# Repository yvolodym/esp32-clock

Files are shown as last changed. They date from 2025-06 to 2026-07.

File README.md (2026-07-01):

# esp32-clock

This project is intended as training for esp8266. The aim of this project is to develop a low-energy clock, developed in C by [espressif](https://www.espressif.com/) with associated PCB in [KiCad](https://www.kicad.org/).

### URI
* https://docs.lvgl.io/master/intro/introduction.html
* https://github.com/espressif/esp-bsp/tree/master/components/lcd/esp_lcd_gc9a01
* https://github.com/espressif/esp-bsp
* https://github.com/lvgl/lv_port_esp32
* https://github.com/lvgl/lvgl_esp32_drivers/blob/master/README.md

### HARDWARE
ESP32-PICO-V3
CR2032

### Software
* https://github.com/espressif/esp-idf/blob/master/examples/peripherals/lcd/spi_lcd_touch/README.md
-------------------------------
* https://github.com/espressif/esp-idf/tree/v5.4/examples/peripherals/lcd/i2c_oled/main
* https://github.com/UsefulElectronics/esp32s3-gc9a01-lvgl/blob/main/main/Kconfig.projbuild
* https://github.com/liyanboy74/gc9a01-esp-idf
* https://github.com/somebox/esp32-GC9A01-round/blob/main/src/main.cpp

### Schematik
* https://embeddedprojects101.com/design-a-battery-powered-stm32-board-with-usb/

### JLCPCB
* https://jlcpcb.com/parts/componentSearch

### Video
* https://www.youtube.com/watch?v=S_p0YV-JlfU

### WIFI Provisioning
* https://docs.espressif.com/projects/esp-idf/en/stable/esp32/api-reference/provisioning/wifi_provisioning.html#
* https://github.com/espressif/esp-idf/blob/master/examples/provisioning/wifi_prov_mgr/README.md

| Pin | Name |
|-----|---|
|IO19 |RST |
|IO10 |SCL |
|IO20 |CS |
|IO21 |DC |
|IO22 |MOSI  |

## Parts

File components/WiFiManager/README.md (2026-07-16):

# WiFiManager

Espressif ESPx WiFi Connection manager with fallback web configuration portal

:warning: This Documentation is out of date, see notes below


















Member to Member Support / Chat

 
 

The configuration portal is of the captive variety, so on various devices it will present the configuration dialogue as soon as you connect to the created access point.

Works with the [ESP8266 Arduino](https://github.com/esp8266/Arduino) and [ESP32 Arduino](https://github.com/espressif/arduino-esp32) platforms.

### Known Issues

* Documentation needs to be updated, see [https://github.com/tzapu/WiFiManager/issues/500](https://github.com/tzapu/WiFiManager/issues/500)
-------

## Contents
 - [How it works](#how-it-works)
 - [Wishlist](#wishlist)
 - [Quick start](#quick-start)
   - Installing
     - [Arduino - Through Library Manager](#install-through-library-manager)
     - [Arduino - From Github](#checkout-from-github)
     - [PlatformIO](#install-using-platformio)
   - [Using](#using)
 - [Documentation](#documentation)
   - [Access Point Password](#password-protect-the-configuration-access-point)
   - [Callbacks](#callbacks)
   - [Configuration Portal Timeout](#configuration-portal-timeout)
   - [On Demand Configuration](#on-demand-configuration-portal)
   - [Custom Parameters](#custom-parameters)
   - [Custom IP Configuration](#custom-ip-configuration)
   - [Filter Low Quality Networks](#filter-networks)
   - [Debug Output](#debug)
 - [Troubleshooting](#troubleshooting)
 - [Releases](#releases)
 - [Contributors](#contributions-and-thanks)

## How It Works
- When your ESP starts up, it sets it up in Station mode and tries to connect to a previously saved Access Point
- if this is unsuccessful (or no previous network saved) it moves the ESP into Access Point mode and spins up a DNS and WebServer (default ip 192.168.4.1)
- using any wifi enabled device with a browser (computer, phone, tablet) connect to the newly created Access Point
- because of the Captive Portal and the DNS server you will either get a 'Join to network' type of popup or get any domain you try to access redirected to the configuration portal
- choose one of the access points scanned, enter password, click save
- ESP will try to connect. If successful, it relinquishes control back to your app. If not, reconnect to AP and reconfigure.
- There are options to change this behavior or manually start the configportal and webportal independantly as well as run them in non blocking mode.

## How It Looks
ESP8266 WiFi Captive Portal Homepage ESP8266 WiFi Captive Portal Configuration

## Wishlist
- [x] remove dependency on EEPROM library
- [x] move HTML Strings to PROGMEM
- [x] cleanup and streamline code (although this is ongoing)
- [x] if timeout is set, extend it when a page is fetched in AP mode
- [x] add ability to configure more parameters than ssid/password
- [x] maybe allow setting ip of ESP after reboot
- [x] add to Arduino Library Manager
- [x] add to PlatformIO
- [ ] add multiple sets of network credentials
- [x] allow users to customize CSS
- [ ] rewrite documentation for simplicity, based on scenarios/goals

### Development
- [x] ESP32 support
- [x] rely on the SDK's built in auto connect more than forcing a connect
- [x] add non blocking mode
- [x] easy customization of strings
- [x] hostname support
- [x] fix various bugs and workarounds for esp SDK issues
- [x] additional info page items
- [x] last status display / faiilure reason
- [x] customizeable menu
- [x] seperate custom params page
- [x] ondemand webportal
- [x] complete refactor of code to segment functions
- [x] wiif scan icons or percentage display
- [x] invert class for dark mode
- [x] more template tokens
- [x] progmem for all strings
- [ ] new callbacks
- [ ] new callouts / filters
- [ ] shared web server instance
- [x] latest esp idf/sdk support
- [x] wm is now non persistent, will not erase or change stored esp config on esp8266
- [x] tons of debugging output / levels
- [ ] disable captiveportal
- [ ] preload wiifscans, faster page loads
- [ ] softap stability fixes when sta is not connected

## Quick Start

### Installing
You can either install through the Arduino Library Manager or checkout the latest changes or a release from github

#### Install through Library Manager
__Currently version 0.8+ works with release 2.4.0 or newer of the [ESP8266 core for Arduino](https://github.com/esp8266/Arduino)__
 - in Arduino IDE got to Sketch/Include Library/Manage Libraries
  Manage Libraries

 - search for WiFiManager
  WiFiManager package

 - click Install and start [using it](#using)

####  Checkout from github
__Github version works with release 2.4.0 or newer of the [ESP8266 core for Arduino](https://github.com/esp8266/Arduino)__
- Checkout library to your Arduino libraries folder

### Using
- Include in your sketch
```cpp
#include <WiFiManager.h>          //https://github.com/tzapu/WiFiManager WiFi Configuration Magic
```

- Initialize library, in your setup function add, NOTEif you are using non blocking you will make sure you create this in global scope or handle appropriatly , it will not work if in setup and using non blocking mode.
```cpp
WiFiManager wifiManager;
```

- Also in the setup function add
```cpp
//first parameter is name of access point, second is the password
wifiManager.autoConnect("AP-NAME", "AP-PASSWORD");
```
if you just want an unsecured access point
```cpp
wifiManager.autoConnect("AP-NAME");
```
or if you want to use and auto generated name from 'ESP' and the esp's Chip ID use
```cpp
wifiManager.autoConnect();
```

After you write your sketch and start the ESP, it will try to connect to WiFi. If it fails it starts in Access Point mode.
While in AP mode, connect to it then open a browser to the gateway IP, default 192.168.4.1, configure wifi, save and it should reboot and connect.

Also see [examples](https://github.com/tzapu/WiFiManager/tree/master/examples).

#### Install Using PlatformIO

[PlatformIO](https://platformio.org/) is an emerging ecosystem for IoT development, and 
is an alternative to using the Arduino IDE. Install `WiFiManager`
using the platformio [library manager](https://docs.platformio.org/en/latest/librarymanager/index.html#librarymanager) in your editor, 
or using the [PlatformIO Core CLI](https://docs.platformio.org/en/latest/core/index.html),
or by adding it to your `platformio.ini` as shown below (recommended approach).

The simplest way is to open the `platformio.ini` file at the root of your project, and `WifiManager` to the common top-level env
`lib_deps` key like so:

```
[env]
lib_deps =
	WiFiManager
```

```
[env]
lib_deps =
	https://github.com/tzapu/WiFiManager.git
```

## Documentation

#### Switch languages for the configuration website
You can switch the language for configuration website during compile time. Default is `LANG_EN` for an english setup. Within PlatformIO add the following compile parameter:
```ini
[env]
build_flags = -D LANG_EN
```
Currently the following language codes are available:
```ini
LANG_DE
LANG_EN
LANG_ES
LANG_FR
LANG_PT
LANG_PT_BR
```

#### Password protect the configuration Access Point
You can and should password protect the configuration access point.  Simply add the password as a second parameter to `autoConnect`.
A short password seems to have unpredictable results so use one that's around 8 characters or more in length.
The guidelines are that a wifi password must consist of 8 to 63 ASCII-encoded characters in the range of 32 to 126 (decimal)
```cpp
wifiManager.autoConnect("AutoConnectAP", "password")
```

#### Callbacks
##### Enter Config mode
Use this if you need to do something when your device enters configuration mode on failed WiFi connection attempt.
Before `autoConnect()`
```cpp
wifiManager.setAPCallback(configModeCallback);
```
`configModeCallback` declaration and example
```cpp
void configModeCallback (WiFiManager *myWiFiManager) {
  Serial.println("Entered config mode");
  Serial.println(WiFi.softAPIP());

  Serial.println(myWiFiManager->getConfigPortalSSID());
}
```

##### Save settings
This gets called when custom parameters have been set **AND** a connection has been established. Use it to set a flag, so when all the configuration finishes, you can save the extra parameters somewhere.

IF YOU NEED TO SAVE PARAMETERS EVEN ON WIFI FAIL OR EMPTY, you must set `setBreakAfterConfig` to true, or else saveConfigCallback will not be called.

```C++
//if this is set, it will exit after config, even if connection is unsuccessful.
    void          setBreakAfterConfig(boolean shouldBreak);
```

See [AutoConnectWithFSParameters Example](https://github.com/tzapu/WiFiManager/tree/master/examples/Parameters/SPIFFS/AutoConnectWithFSParameters).
```cpp
wifiManager.setSaveConfigCallback(saveConfigCallback);
```
`saveConfigCallback` declaration and example
```cpp
//flag for saving data
bool shouldSaveConfig = false;

//callback notifying us of the need to save config
void saveConfigCallback () {
  Serial.println("Should save config");
  shouldSaveConfig = true;
}
```

#### Configuration Portal Timeout
If you need to set a timeout so the ESP doesn't hang waiting to be configured, for instance after a power failure, you can add
```cpp
wifiManager.setConfigPortalTimeout(180);
```
which will wait 3 minutes (180 seconds). When the time passes, the autoConnect function will return, no matter the outcome.
Check for connection and if it's still not established do whatever is needed (on some modules I restart them to retry, on others I enter deep sleep)

#### On Demand Configuration Portal
If you would rather start the configuration portal on demand rather than automatically on a failed connection attempt, then this is for you.

Instead of calling `autoConnect()` which does all the connecting and failover configuration portal setup for you, you need to use `startConfigPortal()`. __Do not use BOTH.__

Example usage
```cpp
void loop() {
  // is configuration portal requested?
  if ( digitalRead(TRIGGER_PIN) == LOW ) {
    WiFiManager wifiManager;
    wifiManager.startConfigPortal("OnDemandAP");
    Serial.println("connected...yeey :)");
  }
}
```
See example for a more complex version. [OnDemandConfigPortal](https://github.com/tzapu/WiFiManager/tree/master/examples/OnDemand/OnDemandConfigPortal)

#### Exiting from the Configuration Portal
Normally, once entered, the configuration portal will continue to loop until WiFi credentials have been successfully entered or a timeout is reached.
If you'd prefer to exit without joining a WiFi network, say becuase you're going to put the ESP into AP mode, then press the "Exit" button
on the main webpage.
If started via `autoConnect` or `startConfigPortal` then it will return `false (portalAbortResult)`

#### Custom Parameters
You can use WiFiManager to collect more parameters than just SSID and password.
This could be helpful for configuring stuff like MQTT host and port, [blynk](http://www.blynk.cc) or [emoncms](http://emoncms.org) tokens, just to name a few.
**You are responsible for saving and loading these custom values.** The library just collects and displays the data for you as a convenience.
Usage scenario would be:
- load values from somewhere (EEPROM/FS) or generate some defaults
- add the custom parameters to WiFiManager using
```cpp
 // id/name, placeholder/prompt, default, length
 WiFiManagerParameter custom_mqtt_server("server", "mqtt server", mqtt_server, 40);
 wifiManager.addParameter(&custom_mqtt_server);

```
- if connection to AP fails, configuration portal starts and you can set /change the values (or use on demand configuration portal)
- once configuration is done and connection is established save config callback() is called
- once WiFiManager returns control to your application, read and save the new values using the `WiFiManagerParameter` object.
```cpp
 mqtt_server = custom_mqtt_server.getValue();
```  
This feature is a lot more involved than all the others, so here are some examples to fully show how it is done.
You should also take a look at adding custom HTML to your form.

- Save and load custom parameters to file system in json form [AutoConnectWithFSParameters](https://github.com/tzapu/WiFiManager/tree/master/examples/Parameters/SPIFFS/AutoConnectWithFSParameters)
- *Save and load custom parameters to EEPROM* (not done yet)

#### Custom IP Configuration
You can set a custom IP for both AP (access point, config mode) and STA (station mode, client mode, normal project state)

##### Custom Access Point IP Configuration
This will set your captive portal to a specific IP should you need/want such a feature. Add the following snippet before `autoConnect()`
```cpp
//set custom ip for portal
wifiManager.setAPStaticIPConfig(IPAddress(10,0,1,1), IPAddress(10,0,1,1), IPAddress(255,255,255,0));
```

##### Custom Station (client) Static IP Configuration
This will make use the specified IP configuration instead of using DHCP in station mode.
```cpp
wifiManager.setSTAStaticIPConfig(IPAddress(192,168,0,99), IPAddress(192,168,0,1), IPAddress(255,255,255,0)); // optional DNS 4th argument
```
There are a couple of examples in the examples folder that show you how to set a static IP and even how to configure it through the web configuration portal.

NOTE: You should fill DNS server if you have HTTP requests with hostnames or syncronize time (NTP). It's the same as gateway ip or a popular (Google DNS: 8.8.8.8).

#### Custom HTML, CSS, Javascript
There are various ways in which you can inject custom HTML, CSS or Javascript into the configuration portal.
The options are:
- inject custom head element
You can use this to any html bit to the head of the configuration portal. If you add a `<style>` element, bare in mind it overwrites the included css, not replaces.
```cpp
wifiManager.setCustomHeadElement("<style>html{filter: invert(100%); -webkit-filter: invert(100%);}</style>");
```
- inject a custom bit of html in the configuration/param form
```cpp
WiFiManagerParameter custom_text("<p>This is just a text paragraph</p>");
wifiManager.addParameter(&custom_text);
```
- inject a custom bit of html in a configuration form element
Just add the bit you want added as the last parameter to the custom parameter constructor.
```cpp
WiFiManagerParameter custom_mqtt_server("server", "mqtt server", "iot.eclipse", 40, " readonly");
wifiManager.addParameter(&custom_mqtt_server);
```

#### Theming
You can customize certain elements of the default template with some builtin classes
```CPP
wifiManager.setClass("invert"); // dark theme
wifiManager.setScanDispPerc(true); // display percentages instead of graphs for RSSI
```
There are additional classes in the css you can use in your custom html , see the example template.

#### Filter Networks
You can filter networks based on signal quality and show/hide duplicate networks.

- If you would like to filter low signal quality networks you can tell WiFiManager to not show networks below an arbitrary quality %;
```cpp
wifiManager.setMinimumSignalQuality(10);
```
will not show networks under 10% signal quality. If you omit the parameter it defaults to 8%;

- You can also remove or show duplicate networks (default is remove).
Use this function to show (or hide) all networks.
```cpp
wifiManager.setRemoveDuplicateAPs(false);
```

#### Debug
Debug is enabled by default on `Serial` in non-stable releases. To disable add before autoConnect/startConfigPortal
```cpp
wifiManager.setDebugOutput(false);
```

You can pass in a custom stream via constructor 
```CPP
WiFiManager wifiManager(Serial1);
```

You can customize the debug level by changing `_debugLevel` in source
options are:
* DEBUG_ERROR
* DEBUG_NOTIFY
* DEBUG_VERBOSE
* DEBUG_DEV
* DEBUG_MAX

## Troubleshooting
If you get compilation errors, more often than not, you may need to install a newer version of the ESP8266 core for Arduino.

Changes added on 0.8 should make the latest trunk work without compilation errors. Tested down to ESP8266 core 2.0.0. **Please update to version 0.8**

I am trying to keep releases working with release versions of the core, so they can be installed through boards manager, but if you checkout the latest version directly from github, sometimes, the library will only work if you update the ESP8266 core to the latest version because I am using some newly added function.

If you connect to the created configuration Access Point but the configuration portal does not show up, just open a browser and type in the IP of the web portal, by default `192.168.4.1`.

If trying to connect ends up in an endless loop, try to add `setConnectTimeout(60)` before `autoConnect();`. The parameter is timeout to try connecting in seconds.

I get stuck in ap mode when the power goes out or modem resets, try a setConfigPortalTimeout(seconds). This will cause the configportal to close after no activity, and you can reboot or attempt reconnection in your code.

## Releases
### 1.0.1

### Development Overview

#### Added Public Methods
`setConfigPortalBlocking`

`setShowStaticFields`

`setCaptivePortalEnable`

`setRestorePersistent`

`setCaptivePortalClientCheck`

`setWebPortalClientCheck`

`startWebPortal`

`stopWebPortal`

`process`

`disconnect`

`erase`

` debugSoftAPConfig`

` debugPlatformInfo`

`setScanDispPerc`

`setHostname`

`setMenu(menu_page_t[])`

`setWiFiAutoReconnect`

` setSTAStaticIPConfig(..,dns)`

`setShowDnsFields`

`getLastConxResult`

`getWLStatusString`

`getModeString`

`getWiFiIsSaved`

`setShowInfoErase`

`setEnableConfigPortal`

`setCountry`

`setClass`

`htmleEtities`

#### WiFiManagerParameter
`WiFiManagerParameter(id,label)`

`WiFiManagerParameter.setValue(value,length)`

`getParameters`

`getParametersCount`

#### Constructors
`WiFiManager(Stream& consolePort)`

#### define flags
❗️  **Defines cannot be set in user sketches**
`#define WM_MDNS       // use MDNS`

`#define WM_FIXERASECONFIG // use erase flash fix, esp8266 2.4.0`

`#define WM_ERASE_NVS // esp32 erase(true) will erase NVS`

`#include <rom/rtc.h> // esp32 info page will show last reset reasons if this file is included`

#### Changes Overview
- ESP32 support ( fairly stable )
- complete refactor of strings `strings_en.h`
- adds new tokens for wifiscan, and some classes (left , invert icons, MSG color)
- adds status callout panel default, primary, special colors
-  adds tons of info on info page, and erase capability
- adds signal icons, replaces percentage ( has hover titles )
- adds labels to all inputs (replaces placeholders)
- all html ( and eventually all strings except debug) moved to `strings_en.h`
- added additional debugging, compressed debug lines, debuglevels
- persistent disabled, and restored via de/con-stuctor (uses `setRestorePersistent`)
- should retain all user modes including AP, should not overwrite or persist user modes or configs,even STA (`storeSTAmode`) (BUGGY)
- ⚠️ return values may have changed depending on portal abort, or timeout ( `portalTimeoutResult`,`portalAbortResult`)
- params memory is auto allocated by increment of `WIFI_MANAGER_MAX_PARAMS(5)` when exceeded, user no longer needs to specify this at all.
- addparameter now returns bool, and it returns false if param ID is not alphanum [0-9,A-Z,a-z,_]
- param field ids allow {I} token to use param_n instead of string in case someones wants to change this due to i18n or character issues
- provides `#DEFINE FIXERASECONFIG` to help deal with https://github.com/esp8266/Arduino/pull/3635
- failure reason reporting on portal
- set esp8266 sta hostname, esp32 sta+ap hostname ( DHCP client id)
- pass in debug stream in constructor WiFiManager(Stream& consolePort)
- you can force ip fields off with showxfields(false) if you set _disableIpFields=true
- param menu/page (setup) added to separate params from wifi page, handled automatically by setMenu
- set custom root menu
- disable configportal on autoconnect
- wm parameters init is now protected, allowing child classes, example included
- wifiscans are precached and async for faster page loads, refresh forces rescan
- adds esp32 gettemperature ( currently commented out, useful for relative measurement only )

#### 0.12
- removed 204 header response
- fixed incompatibility with other libs using isnan and other std:: functions without namespace

##### 0.11
- a lot more reliable reconnecting to networks
- custom html in custom parameters (for read only params)
- custom html in custom parameter form (like labels)
- custom head element (like custom css)
- sort networks based on signal quality
- remove duplicate networks

##### 0.10
- some css changes
- bug fixes and speed improvements
- added an alternative to waitForConnectResult() for debugging
- changed `setTimeout(seconds)` to `setConfigPortalTimeout(seconds)`

### Contributions and thanks
The support and help I got from the community has been nothing short of phenomenal. I can't thank you guys enough. This is my first real attept in developing open source stuff and I must say, now I understand why people are so dedicated to it, it is because of all the wonderful people involved.

__THANK YOU__

The esp8266 and esp32 arduino and idf maintainers!

[Shawn A aka tablatronix](https://github.com/tablatronix)

[liebman](https://github.com/liebman)

[Evgeny Dontsov](https://github.com/dontsovcmc)

[Chris Marrin](https://github.com/cmarrin)

[bbx10](https://github.com/bbx10)

[kentaylor](https://github.com/kentaylor)

[Maximiliano Duarte](https://github.com/domonetic)

[alltheblinkythings](https://github.com/alltheblinkythings)

[Niklas Wall](https://github.com/niklaswall)

[Jakub Piasecki](https://github.com/zaporylie)

[Peter Allan](https://github.com/alwynallan)

[John Little](https://github.com/j0hnlittle)

[markaswift](https://github.com/markaswift)

[franklinvv](https://github.com/franklinvv)

[Alberto Ricci Bitti](https://github.com/riccibitti)

[SebiPanther](https://github.com/SebiPanther)

[jonathanendersby](https://github.com/jonathanendersby)

[walthercarsten](https://github.com/walthercarsten)

And countless others

#### Inspiration
 * http://www.esp8266.com/viewtopic.php?f=29&t=2520
 * https://github.com/chriscook8/esp-arduino-apboot
 * https://github.com/esp8266/Arduino/tree/master/libraries/DNSServer/examples/CaptivePortalAdvanced
 * Built by AlexT https://github.com/tzapu

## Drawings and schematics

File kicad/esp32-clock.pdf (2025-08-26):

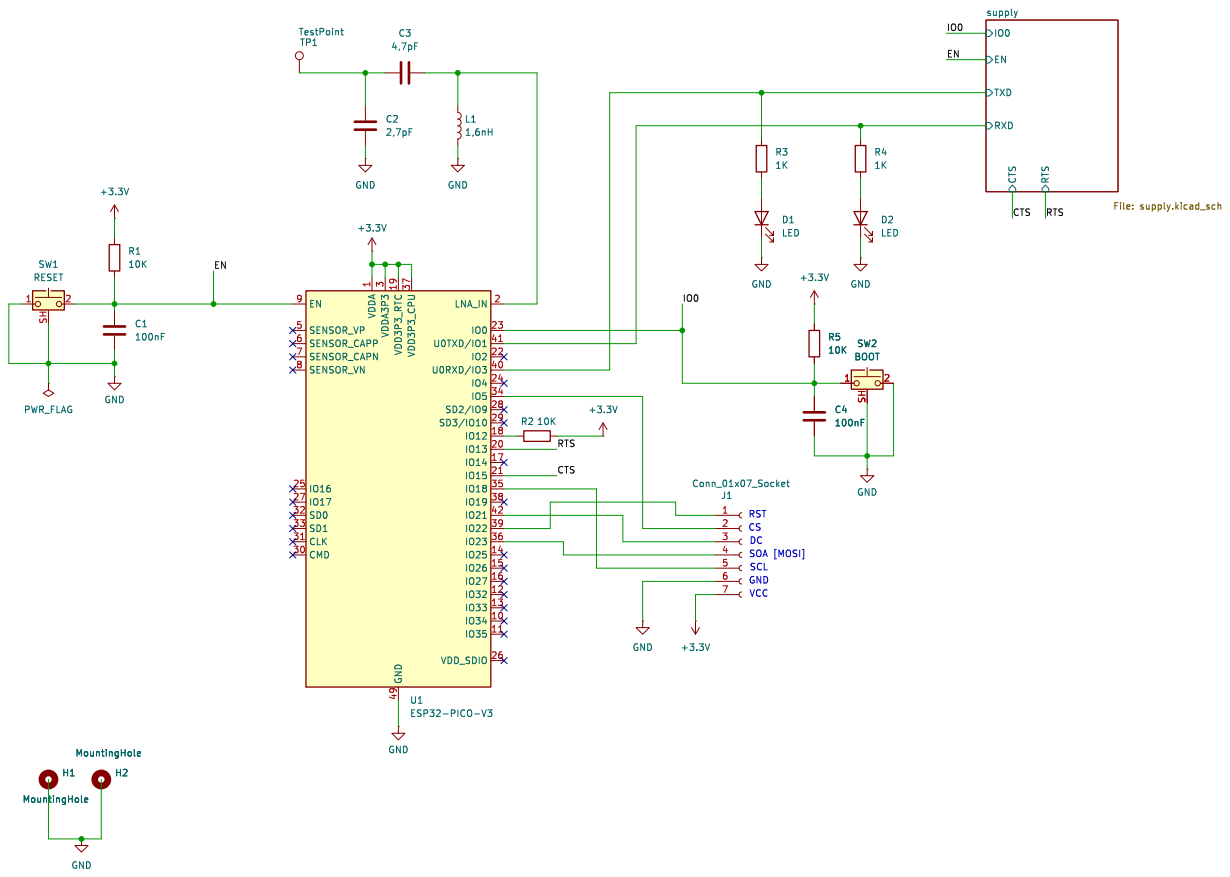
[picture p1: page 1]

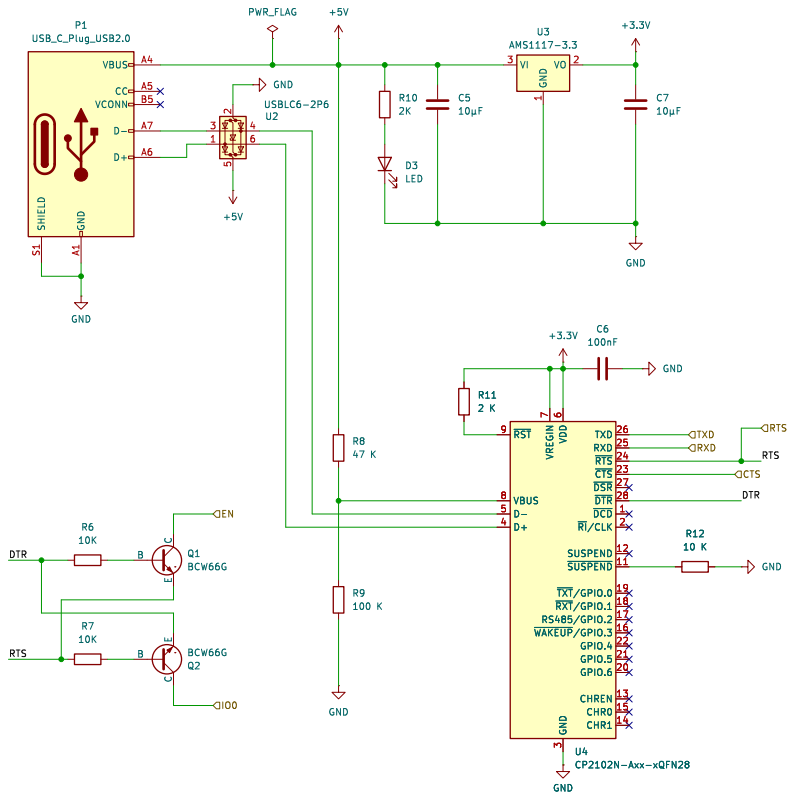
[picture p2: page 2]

3 TXD 26 RXD 25 ~{RTS} 24 ~{CTS} 23 ~{DSR} 27 ~{DTR} 28 ~{DCD}1 ~{RI}/CLK2 SUSPEND 12 ~{SUSPEND}11 ~{TXT}/GPIO.019 ~{RXT}/GPIO.118 RS485/GPIO.2 17 ~{WAKEUP}/GPIO.316 GPIO.4 22 GPIO.5 21 GPIO.6 20 CHREN 13 CHR0 15 CHR1 14 U4 CP2102N-Axx-xQFN28 GND

3 TXD 26 RXD 25 ~{RTS} 24 ~{CTS} 23 ~{DSR} 27 ~{DTR} 28 ~{DCD}1 ~{RI}/CLK2 SUSPEND 12 ~{SUSPEND}11 ~{TXT}/GPIO.019 ~{RXT}/GPIO.118 RS485/GPIO.2 17 ~{WAKEUP}/GPIO.316 GPIO.4 22 GPIO.5 21 GPIO.6 20 CHREN 13 CHR0 15 CHR1 14 GND

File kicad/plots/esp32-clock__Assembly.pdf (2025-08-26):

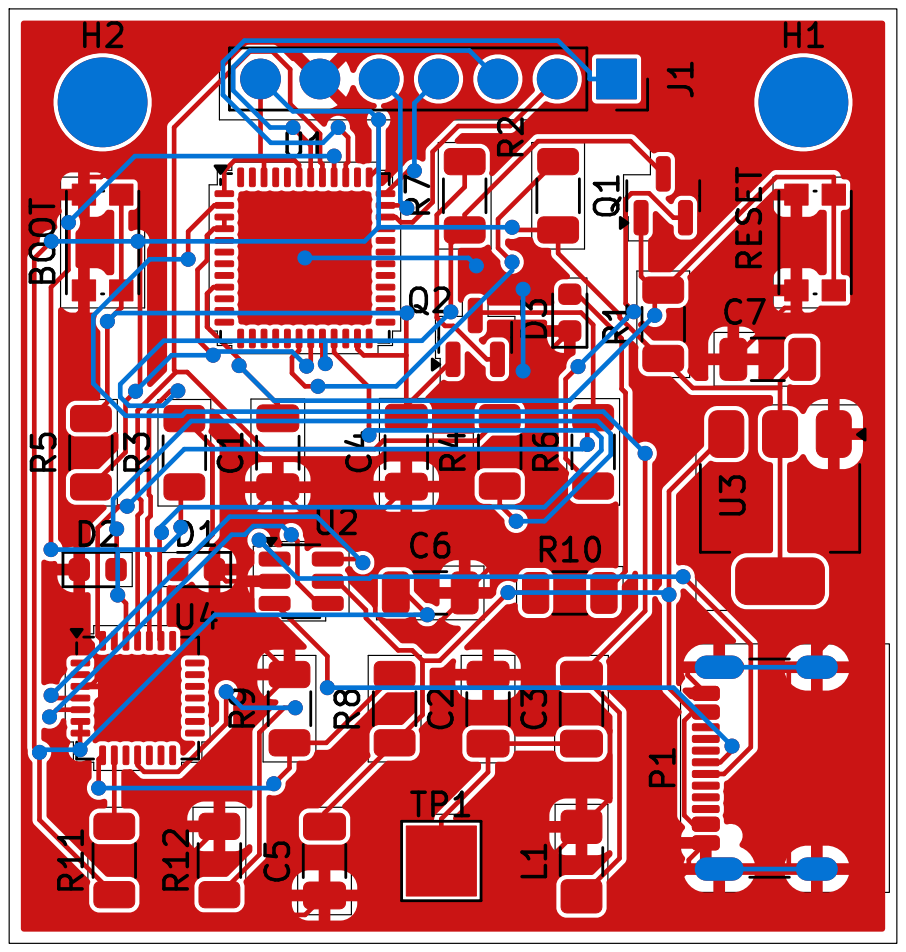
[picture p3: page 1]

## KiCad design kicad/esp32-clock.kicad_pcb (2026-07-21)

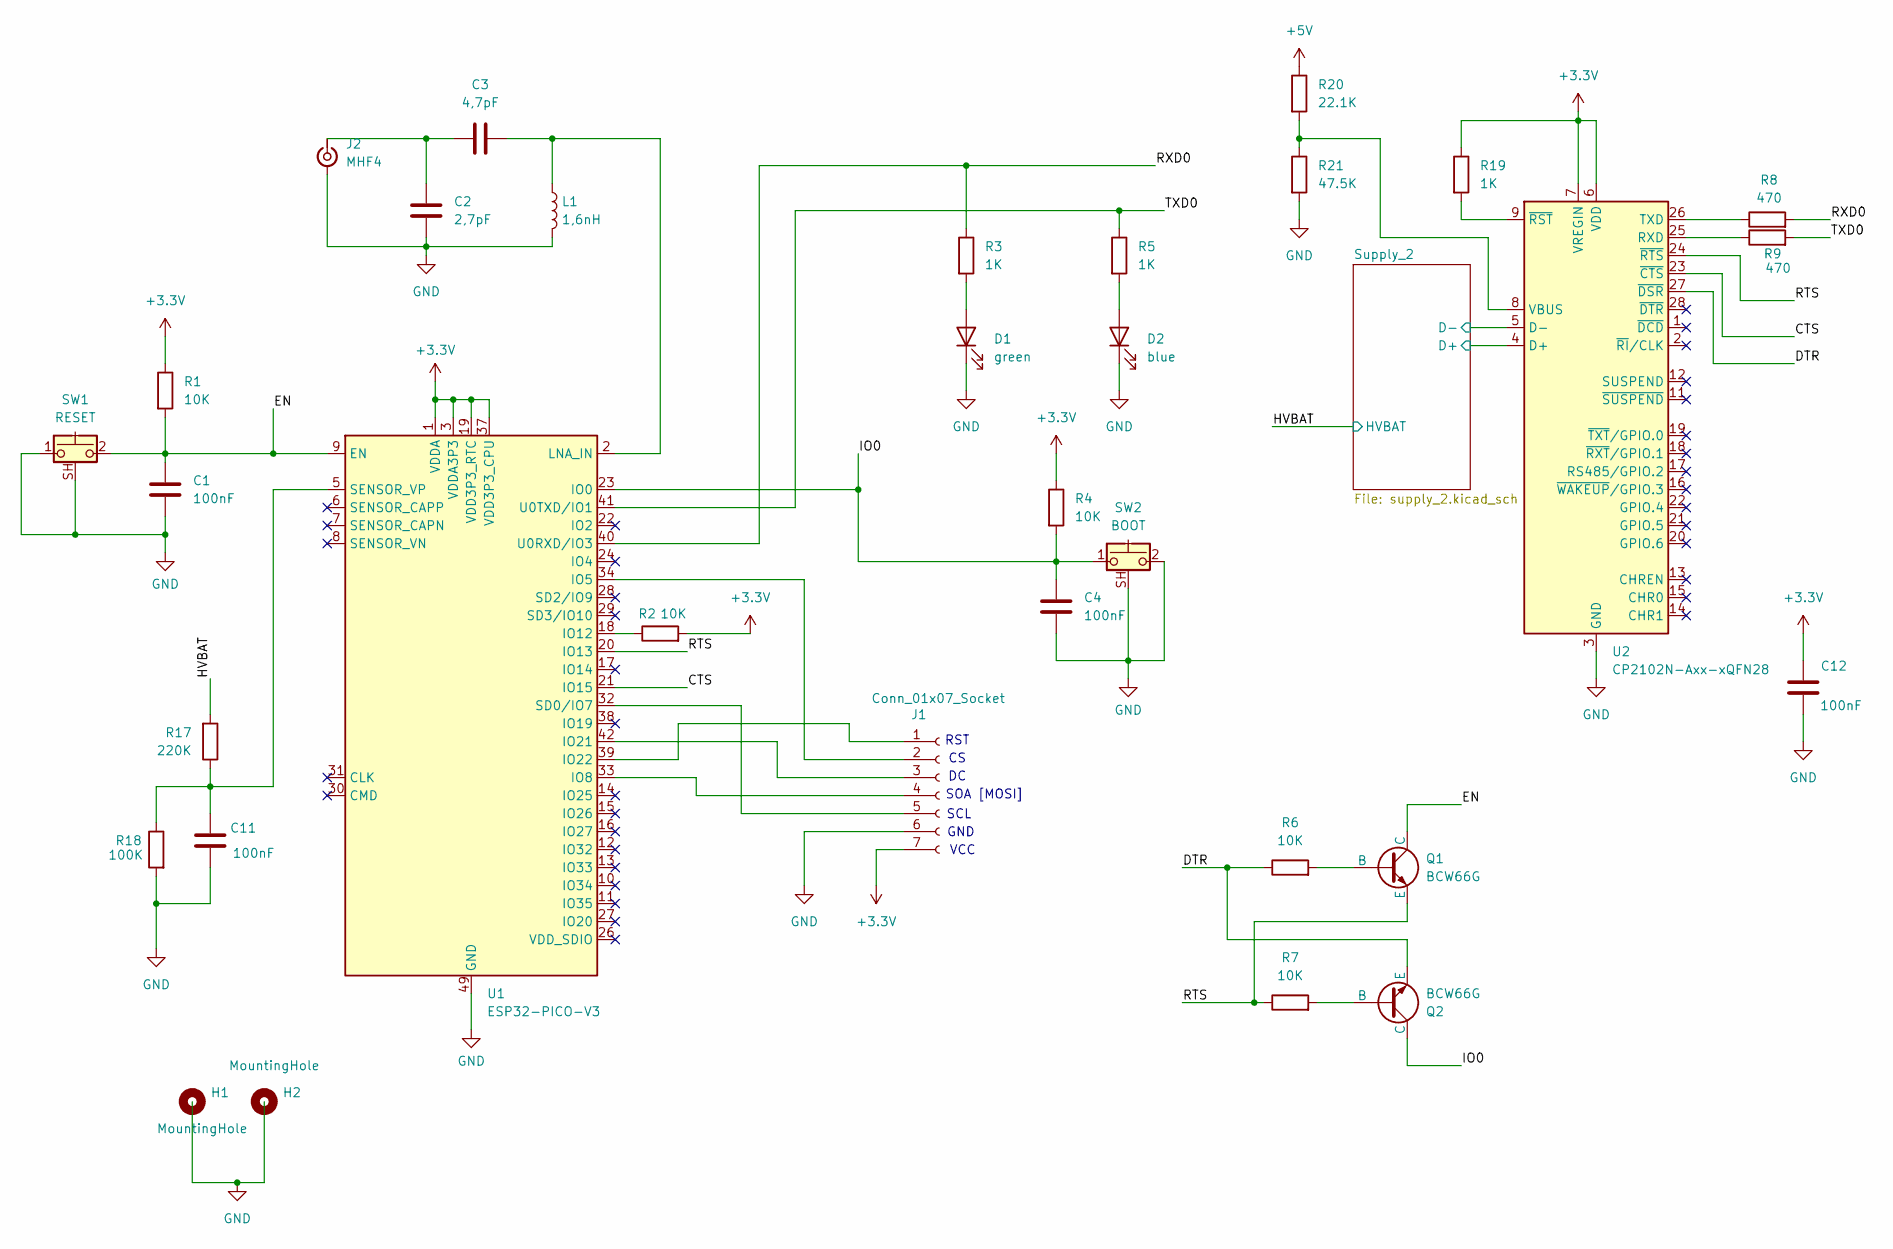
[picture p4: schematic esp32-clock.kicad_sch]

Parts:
C1, C4, C11, C12: 100nF; C_0805_2012Metric
C2: 2,7pF; C_0805_2012Metric
C3: 4,7pF; C_0805_2012Metric
D1: green; D_0805_2012Metric
D2: blue; D_0805_2012Metric
H1, H2: MountingHole; MountingHole_2.2mm_M2_DIN965_Pad
J1: Conn_01x07_Socket; PinSocket_1x07_P2.54mm_Vertical
J2: MHF4
L1: 1,6nH; D_0805_2012Metric
Q1, Q2: BCW66G; SOT-23
R1, R2, R4: 10K; R_0805_2012Metric
R3, R5, R19: 1K; R_0805_2012Metric
R6, R7: 10K; R_0805_2012Metric; LCSC C25819
R8, R9: 470; R_0805_2012Metric; LCSC C25819
R17: 220K; R_0805_2012Metric
R18: 100K; R_0805_2012Metric
R20: 22.1K; R_0805_2012Metric
R21: 47.5K; R_0805_2012Metric
SW1: RESET; SW_Push_1P1T_NO_CK_KMR2
SW2: BOOT; SW_Push_1P1T_NO_CK_KMR2
U1: ESP32-PICO-V3; QFN-48-1EP_7x7mm_P0.5mm_EP5.3x5.3mm
U2: CP2102N-Axx-xQFN28; QFN-28-1EP_5x5mm_P0.5mm_EP3.35x3.35mm

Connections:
+3.3V: C12.1, J1.7, R1.1, R2.2, R4.1, R19.1, U1.1 (VDDA), U1.3 (VDDA3P3), U1.4 (VDDA3P3), U1.19 (VDD3P3_RTC), U1.37 (VDD3P3_CPU), U1.43 (VDDA), U1.46 (VDDA), U2.6 (VDD), U2.7 (VREGIN); also elsewhere on the board
+5V: R20.1; also elsewhere on the board
/CTS: U1.21 (IO15), U2.23 (~CTS)
/DTR: Q2.3 (E), R6.1, U2.27 (~DSR)
/EN: C1.1, Q1.1 (C), R1.2, SW1.2, U1.9 (EN)
/HVBAT: R17.2; also elsewhere on the board
/IO0: C4.1, Q2.1 (C), R4.2, SW2.1, U1.23 (IO0)
/RTS: Q1.3 (E), R7.1, U1.20 (IO13), U2.24 (~RTS)
/RXD0: R3.1, R8.2, U1.40 (U0RXD/IO3)
/Supply_2/D+: U2.4 (D+); also elsewhere on the board
/Supply_2/D-: U2.5 (D-); also elsewhere on the board
/TXD0: R5.1, R9.2, U1.41 (U0TXD/IO1)
GND: C1.2, C2.2, C4.2, C11.2, C12.2, D1.1 (K), D2.1 (K), J1.6, J2.2 (GND), L1.2, R18.2, R21.2, SW1.1, SW1.SH (B), SW2.2, SW2.SH (B), U1.49 (GND), U2.3 (GND), U2.29 (GND); also elsewhere on the board
unnamed: D1.2 (A), R3.2
unnamed: D2.2 (A), R5.2
unnamed: J1.1, U1.39 (IO22)
unnamed: J1.2, U1.34 (IO5)
unnamed: J1.3, U1.42 (IO21)
unnamed: J1.4, U1.33 (IO8)
unnamed: J1.5, U1.32 (SD0/IO7)
unnamed: C2.1, C3.1, J2.1 (SIGNAL)
unnamed: Q1.2 (B), R6.2
unnamed: Q2.2 (B), R7.2
unnamed: R2.1, U1.18 (IO12)
unnamed: C3.2, L1.1, U1.2 (LNA_IN)
unnamed: C11.1, R17.1, R18.1, U1.5 (SENSOR_VP)
unnamed: R9.1, U2.25 (RXD)
unnamed: R8.1, U2.26 (TXD)
unnamed: R20.2, R21.1, U2.8 (VBUS)
unnamed: R19.2, U2.9 (~RST)

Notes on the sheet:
RST
SCL
VCC
GND
SOA [MOSI]

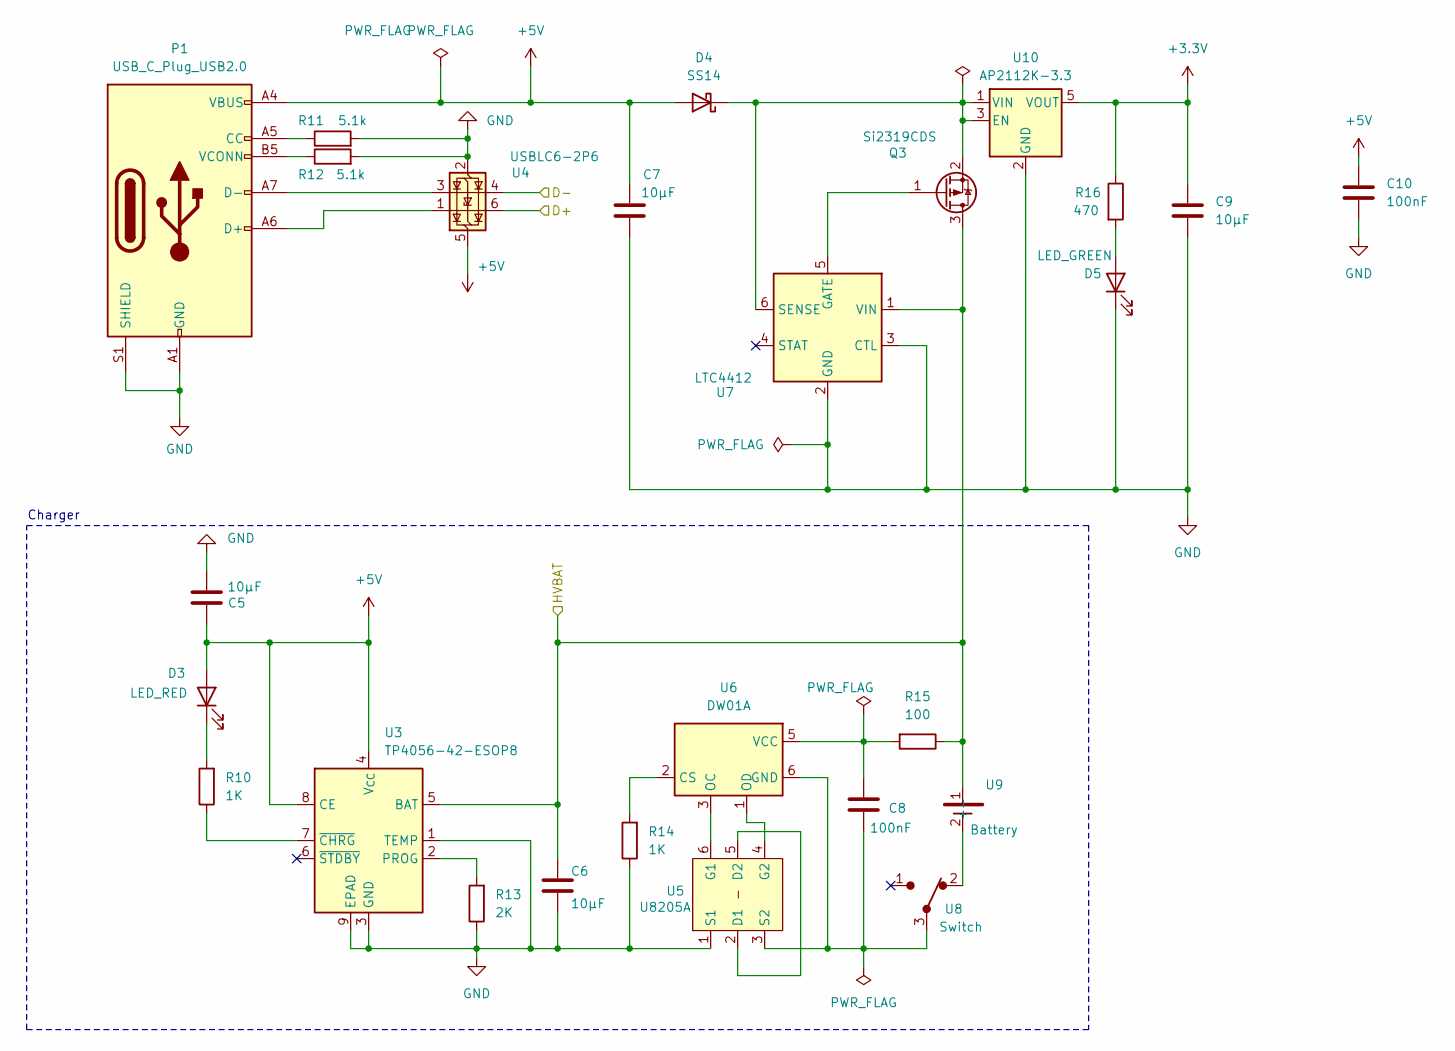
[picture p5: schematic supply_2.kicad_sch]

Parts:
C5, C6, C7, C9: 10µF; C_0805_2012Metric
C8, C10: 100nF; C_0805_2012Metric
D3: LED_RED; D_0805_2012Metric
D4: SS14; D_SMA
D5: LED_GREEN; D_0805_2012Metric
P1: USB_C_Plug_USB2.0; USB_C_Receptacle_GCT_USB4105-xx-A_16P_TopMnt_Horizontal; LCSC C456012
Q3: Si2319CDS; SOT-23
R10, R14: 1K; R_0805_2012Metric
R11, R12: 5.1k; R_0805_2012Metric
R13: 2K; R_0805_2012Metric
R15: 100; R_0805_2012Metric
R16: 470; R_0805_2012Metric
U3: TP4056-42-ESOP8; SOIC-8-1EP_3.9x4.9mm_P1.27mm_EP2.41x3.3mm_ThermalVias
U4: USBLC6-2P6; SOT-23-6
U5: U8205A; SOT-23-6
U6: DW01A; SOT-23-6
U7: LTC4412; TSOT-23-6
U8: Switch; SW_SPDT_PCM12
U9: Battery; CR2032
U10: AP2112K-3.3; SOT-23-5

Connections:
+3.3V: C9.1, R16.1, U10.5 (VOUT); also elsewhere on the board
+5V: C5.1, C7.1, C10.2, D3.2 (A), D4.2 (A), P1.A4 (VBUS), P1.A9 (VBUS), P1.B4 (VBUS), P1.B9 (VBUS), U3.4 (V_{CC}), U3.8 (CE), U4.5 (VBUS); also elsewhere on the board
/HVBAT: C6.1, Q3.3 (D), R15.1, U3.5 (BAT), U7.1 (VIN), U9.1 (+); also elsewhere on the board
/Supply_2/D+: U4.6 (I/O1); also elsewhere on the board
/Supply_2/D-: U4.4 (I/O2); also elsewhere on the board
GND: C5.2, C6.2, C7.2, C9.2, C10.1, D5.1 (K), P1.A1 (GND), P1.A12 (GND), P1.B1 (GND), P1.B12 (GND), P1.S1 (SHIELD), R11.2, R12.2, R13.1, R14.1, U3.1 (TEMP), U3.3 (GND), U3.9 (EPAD), U4.2 (GND), U5.1 (S1), U7.2 (GND), U7.3 (CTL), U10.2 (GND); also elsewhere on the board
unnamed: D3.1 (K), R10.2
unnamed: D4.1 (K), Q3.2 (S), U7.6 (SENSE), U10.1 (VIN), U10.3 (EN)
unnamed: D5.2 (A), R16.2
unnamed: P1.A5 (CC), R11.1
unnamed: P1.A6 (D+), U4.1 (I/O1)
unnamed: P1.A7 (D-), U4.3 (I/O2)
unnamed: P1.B5 (VCONN), R12.1
unnamed: Q3.1 (G), U7.5 (GATE)
unnamed: R13.2, U3.2 (PROG)
unnamed: R10.1, U3.7 (~CHRG)
unnamed: U5.2 (D1), U5.5 (D2)
unnamed: U5.6 (G1), U6.3 (OC)
unnamed: U5.4 (G2), U6.1 (OD)
unnamed: C8.1, U5.3 (S2), U6.6 (GND), U8.3
unnamed: R14.2, U6.2 (CS)
unnamed: C8.2, R15.2, U6.5 (VCC)
unnamed: U8.2, U9.2 (-)

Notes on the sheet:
Charger

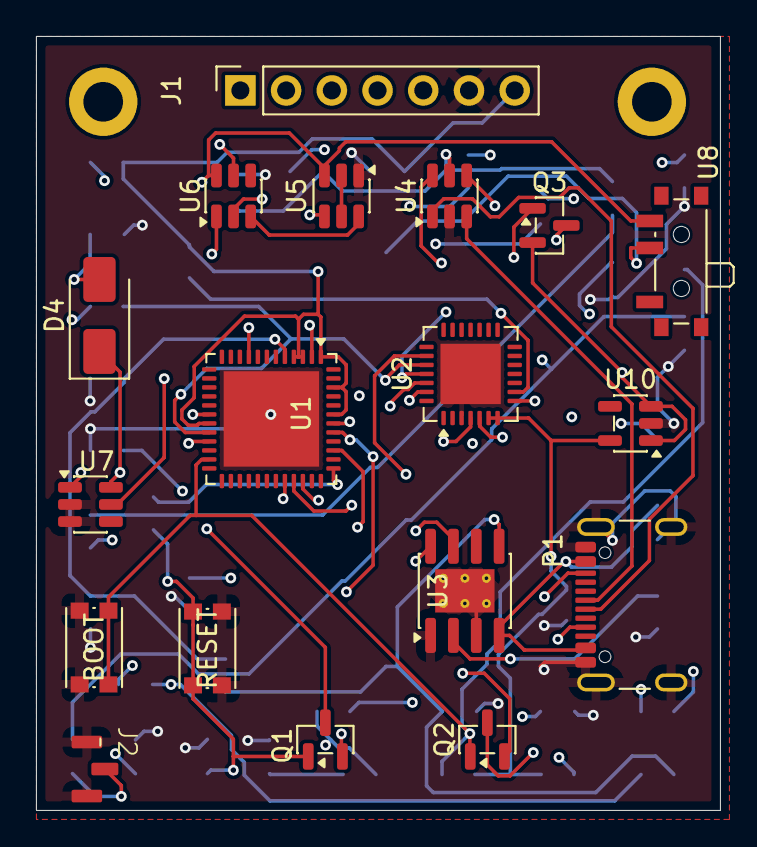
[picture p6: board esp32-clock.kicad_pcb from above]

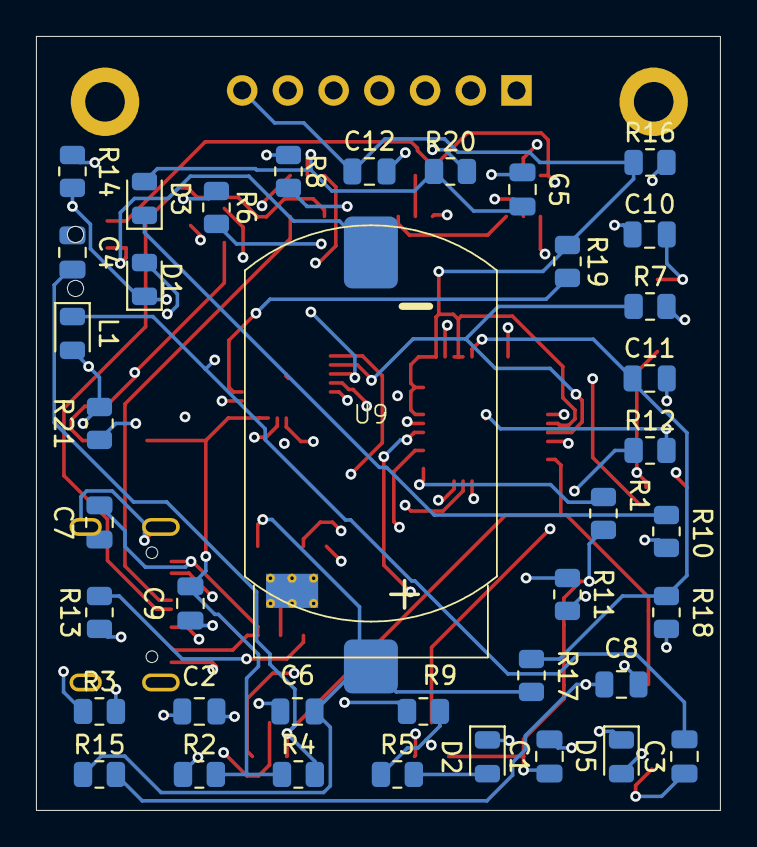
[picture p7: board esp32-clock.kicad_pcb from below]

Board: 4 copper layers, 38.0 x 43.0 mm, 59 parts (39 on the bottom side), 47 nets.

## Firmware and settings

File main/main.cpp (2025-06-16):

#include <Arduino.h>
#include <WiFiManager.h>
#include "time.h"
#include <FS.h>
#include <SPI.h>
#include <TFT_eSPI.h>     // https://github.com/Bodmer/TFT_eSPI
#include "WifiTimeLib.h"
#include "MaliBold60.h"
#include "MaliBold90.h"
#include "FinalFrontier28.h"
#include "NotoSansBold15.h"
#include "NotoSansBold36.h"



// Timezone config
/* 
  Find your zone (https://remotemonitoringsystems.ca/time-zone-abbreviations.php)
  Or see https://github.com/nayarsystems/posix_tz_db/blob/master/zones.csv for more codes for your region
  
  For example: USA eastern time: "EST5EDT,M3.2.0,M11.1.0", Central EU time: "CET-1CEST,M3.5.0,M10.5.0/3"
  Pool can be "pool.ntp.org" or something more local
*/
// Set up WiFI and time sync, replace these with your own time settings (NTP server and timezone)
WifiTimeLib wifiTimeLib("ch.pool.ntp.org", "CET-1CEST-2,M3.5.0/02:00:00,M10.5.0/03:00:00"); // Switzerland


// Font files are stored in SPIFFS (flash ram)
#define FS_NO_GLOBALS

TFT_eSPI tft = TFT_eSPI();  // Invoke library, pins defined in User_Setup.h
TFT_eSprite digital_face_hours = TFT_eSprite(&tft);
TFT_eSprite digital_face_minutes = TFT_eSprite(&tft);
TFT_eSprite analog_face = TFT_eSprite(&tft);

#define CLOCK_X_POS 118
#define CLOCK_Y_POS 118

#define CLOCK_FG   TFT_LIGHTGREY
#define CLOCK_BG   TFT_BROWN
#define SECCOND_FG TFT_YELLOW
#define LABEL_FG   TFT_RED

#define CLOCK_R       240.0f / 2.0f // Clock face radius (float type)
#define H_HAND_LENGTH CLOCK_R/2.2f
#define M_HAND_LENGTH CLOCK_R/1.5f
#define S_HAND_LENGTH CLOCK_R/1.2f

// Calculate 1 second increment angles. Hours and minute hand angles
// change every second so we see smooth sub-pixel movement
#define SECOND_ANGLE 360.0 / 60.0
#define MINUTE_ANGLE SECOND_ANGLE / 60.0
#define HOUR_ANGLE   MINUTE_ANGLE / 12.0

// Screen width and height
#define SCREEN_W 240
#define SCREEN_H 240

// handle multiple displays via CS pin
#define num_displays 2
uint8_t display_cs_pins[num_displays] = { 20, 20 };
uint16_t bg_colors[num_displays] = {TFT_BLUE, TFT_DARKGREEN};

// Time 
tm timeinfo;
time_t now;
int hour = 0;
int minute = 0;
int second = 0;


// =========================================================================
// Get coordinates of end of a line, pivot at x,y, length r, angle a
// =========================================================================
// Coordinates are returned to caller via the xp and yp pointers
#define DEG2RAD 0.0174532925
void getCoord(int16_t x, int16_t y, float *xp, float *yp, int16_t r, float a)
{
  float sx1 = cos( (a - 90) * DEG2RAD);
  float sy1 = sin( (a - 90) * DEG2RAD);
  *xp =  sx1 * r + x;
  *yp =  sy1 * r + y;
}

// =========================================================================
// Draw the clock face in the sprite
// =========================================================================
static void renderDigitalFace(float t, uint16_t bg_color) {
  static int last_hr = 1000;
  char cnum[10];

  // update hours
  if (last_hr != (int)t/3600){
    last_hr = (int)t/3600;
    digital_face_hours.fillSprite(bg_color);
    digital_face_hours.setTextColor(CLOCK_FG, bg_color);  
    digital_face_hours.setTextDatum(MR_DATUM);
    snprintf(cnum, 10, "%02d", (int)t/3600);  // hours
    digital_face_hours.drawString(cnum, digital_face_hours.width()-2, digital_face_hours.height()/2);    
    digital_face_hours.pushSprite(2, tft.height()/2 - digital_face_hours.height()/2); 
  }
  
  // update minutes and seconds
  digital_face_minutes.fillSprite(bg_color);
  digital_face_minutes.setTextColor(TFT_ORANGE, bg_color);  
  digital_face_minutes.setTextDatum(ML_DATUM);
  // minutes
  snprintf(cnum, 10, "%02d", (int)t/60 % 60);
  digital_face_minutes.drawString(cnum, 0, digital_face_minutes.height()*0.3);
  digital_face_minutes.setTextColor(TFT_SKYBLUE, bg_color);  
  // seconds
  snprintf(cnum, 10, "%02d", (int)floor(t) % 60);
  digital_face_minutes.drawString(cnum, 0, digital_face_minutes.height()*0.7);

  digital_face_minutes.pushSprite(tft.width()/1.8, tft.height()/2 - digital_face_minutes.height()/2); 
}

// =========================================================================
// Draw the clock face in the sprite
// =========================================================================
static void renderAnalogFace(float t, uint16_t bg_color) {
  float h_angle = t * HOUR_ANGLE;
  float m_angle = t * MINUTE_ANGLE;
  float s_angle = t * SECOND_ANGLE;
  
  // The face is completely redrawn - this can be done quickly
  analog_face.fillSprite(bg_color);

  // Set text datum to middle centre and the colour
  analog_face.setTextDatum(MC_DATUM);

  // The background colour will be read during the character rendering
  analog_face.setTextColor(CLOCK_FG, bg_color);

  // Text offset adjustment
  constexpr uint32_t dialOffset = CLOCK_R - 15;

  float xp = 0.0, yp = 0.0; // Use float pixel position for smooth AA motion

  // Draw digits around clock perimeter
  for (uint32_t h = 1; h <= 12; h++) {
    getCoord(CLOCK_R, CLOCK_R, &xp, &yp, dialOffset, h * 360.0 / 12);
    analog_face.drawNumber(h, xp, 2 + yp);
  }

  // Add text (could be digital time...)
  analog_face.setTextColor(LABEL_FG, bg_color);
  //face.drawString("TFT_eSPI", CLOCK_R, CLOCK_R * 0.75);

  // Draw minute hand
  getCoord(CLOCK_R, CLOCK_R, &xp, &yp, M_HAND_LENGTH, m_angle);
  analog_face.drawWideLine(CLOCK_R, CLOCK_R, xp, yp, 8.0f, CLOCK_FG);
  analog_face.drawWideLine(CLOCK_R, CLOCK_R, xp, yp, 4.0f, TFT_GREEN);

  // Draw hour hand
  getCoord(CLOCK_R, CLOCK_R, &xp, &yp, H_HAND_LENGTH, h_angle);
  analog_face.drawWideLine(CLOCK_R, CLOCK_R, xp, yp, 8.0f, CLOCK_FG);
  analog_face.drawWideLine(CLOCK_R, CLOCK_R, xp, yp, 4.0f, TFT_GREENYELLOW);

  // Draw the central pivot circle
  analog_face.fillSmoothCircle(CLOCK_R, CLOCK_R, 8, CLOCK_FG);

  // Draw second hand
  getCoord(CLOCK_R, CLOCK_R, &xp, &yp, S_HAND_LENGTH, s_angle);
  analog_face.drawWedgeLine(CLOCK_R, CLOCK_R, xp, yp, 3.5, 1.5, SECCOND_FG);
  analog_face.pushSprite(0, 0, TFT_TRANSPARENT);
}


// =========================================================================
// Setup displays
// =========================================================================

void setupDisplays(){
  for (int i=0; i < num_displays; i++){
    pinMode(display_cs_pins[i], OUTPUT);
    digitalWrite(display_cs_pins[i],HIGH);
  }
  
  // Create the clock face sprite
  //face.setColorDepth(8); // 8 bit will work, but reduces effectiveness of anti-aliasing
  digital_face_minutes.createSprite(SCREEN_W / 2, SCREEN_H / 2);
  digital_face_minutes.loadFont(MaliBold60);

  digital_face_hours.createSprite(SCREEN_W / 2, SCREEN_H / 2);  
  digital_face_hours.loadFont(MaliBold90);

  analog_face.createSprite(SCREEN_W, SCREEN_H);
  analog_face.loadFont(Final_Frontier_28); // prepare for analog updates afterwards

  // Initialize displays
  for (int i=0; i < num_displays; i++){
    digitalWrite(display_cs_pins[i],LOW);
  }
  // Initialise the screen
  tft.init();    
  // Ideally set orientation for good viewing angle range because
  // the anti-aliasing effectiveness varies with screen viewing angle
  // Usually this is when screen ribbon connector is at the bottom
  tft.setRotation(0);
  tft.fillScreen(TFT_BLACK);

  for (int i=0; i < num_displays; i++){
    digitalWrite(display_cs_pins[i],HIGH);
  }
    /*
  digitalWrite(display_cs_pins[1], LOW);
  tft.fillSmoothCircle( CLOCK_R - 1, CLOCK_R - 1, CLOCK_R, bg_colors[1] );
  digitalWrite(display_cs_pins[1], HIGH);
  */
}

// =========================================================================
// Setup
// =========================================================================
uint32_t targetTime = 0;    // Time for next tick
void setup() {
  Serial.begin(115200);
  delay(500);
  Serial.println("Booting...");

  if (!SPIFFS.begin(true)) {
    Serial.println("SPIFFS initialisation failed!");
    while (1) yield(); // Stay here twiddling thumbs waiting
  }
  else {   
    Serial.println("SPIFFS initialised successfully.");
  }

  Serial.println("\r\nInitialisation done.");

  setupDisplays();

  // Connect to WiFi
  if (wifiTimeLib.connectToWiFi("ESP32-Clock", &tft)) {
    delay(500);
    Serial.println("getting current time...");
    // get NTP time
    if (wifiTimeLib.getNTPtime(10)) {  // wait up to 10sec to sync
      Serial.println("Time sync complete");
    } else {
      Serial.println("Error: NTP time update failed!");
    }
  } else {
    Serial.println("ERROR: WiFi connect failure");
  }

  targetTime = millis();
}

// =========================================================================
// Loop
// =========================================================================
int fps=18;                 // frame rate counter, start val is an estimate
float avg_fps=18.0;         // running average across 2 loop samples
float time_secs;            // time in seconds+ms sent to rendering functions
int last_second = 0;        // for checking when to update the digital clock
int ms_offset = 0;          // offset of millis() since start of the last sec

void loop() {
  long m = millis();
  
  if (targetTime < m) {   
    // schedule next tick time for smoother movement
    targetTime = m + 3;

    // Update time periodically
    time(&now);
    localtime_r(&now, &timeinfo);
    int secs = timeinfo.tm_sec;
    time_secs = timeinfo.tm_hour * 3600
              + timeinfo.tm_min * 60 
              + secs;
/*
    if (secs != last_second){ 
      ms_offset = m;
      last_second = secs;

      // digital clock
      digitalWrite(display_cs_pins[1], LOW);
      renderDigitalFace(time_secs, bg_colors[1]);
      digitalWrite(display_cs_pins[1], HIGH);
    } 
*/
    if (secs != last_second){ 
      ms_offset = m;
      last_second = secs;

      // digital clock
      digitalWrite(display_cs_pins[1], LOW);
      //renderAnalogFace(time_secs, bg_colors[1]);
      renderDigitalFace(time_secs, bg_colors[1]);
      digitalWrite(display_cs_pins[1], HIGH);
    } 

    // analog clock
    digitalWrite(display_cs_pins[0], LOW);
    //renderAnalogFace(time_secs + (millis() - ms_offset)/1000.0, bg_colors[1]);
    renderDigitalFace(time_secs, bg_colors[1]);
    digitalWrite(display_cs_pins[0], HIGH);

    // Keep track of frame rate and use it to keep the animation consistent
    fps++;

    if (millis() % 3000 == 0){
        // report FPS every 3 seconds
        Serial.print(" FPS > ");
        Serial.println(fps);
        avg_fps = (avg_fps + fps)/2;
        fps = 0;
    }

  }
}

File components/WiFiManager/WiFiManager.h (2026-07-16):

/**
 * WiFiManager.h
 * 
 * WiFiManager, a library for the ESP8266/Arduino platform
 * for configuration of WiFi credentials using a Captive Portal
 * 
 * @author Creator tzapu
 * @author tablatronix
 * @version 0.0.0
 * @license MIT
 */


#ifndef WiFiManager_h
#define WiFiManager_h

#if defined(ESP8266) || defined(ESP32)

#ifdef ESP8266
#include <core_version.h>
#endif

#include <vector>

// #define WM_MDNS            // includes MDNS, also set MDNS with sethostname
// #define WM_FIXERASECONFIG  // use erase flash fix
// #define WM_ERASE_NVS       // esp32 erase(true) will erase NVS 
// #define WM_RTC             // esp32 info page will include reset reasons

// #define WM_JSTEST                      // build flag for enabling js xhr tests
// #define WIFI_MANAGER_OVERRIDE_STRINGS // build flag for using own strings include

#ifdef ARDUINO_ESP8266_RELEASE_2_3_0
#warning "ARDUINO_ESP8266_RELEASE_2_3_0, some WM features disabled" 
// @todo check failing on platform = espressif8266@1.7.3
#define WM_NOASYNC         // esp8266 no async scan wifi
#define WM_NOCOUNTRY       // esp8266 no country
#define WM_NOAUTH          // no httpauth
#define WM_NOSOFTAPSSID    // no softapssid() @todo shim
#endif

// #ifdef CONFIG_IDF_TARGET_ESP32S2
// #warning ESP32S2
// #endif

// #ifdef CONFIG_IDF_TARGET_ESP32C3
// #warning ESP32C3
// #endif

// #ifdef CONFIG_IDF_TARGET_ESP32S3
// #warning ESP32S3
// #endif

// #if defined(ARDUINO_ESP32S3_DEV) || defined(CONFIG_IDF_TARGET_ESP32S3)
// #warning "WM_NOTEMP"
// #define WM_NOTEMP // disabled temp sensor, have to determine which chip we are on
// #endif

// #include "soc/efuse_reg.h" // include to add efuse chip rev to info, getChipRevision() is almost always the same though, so not sure why it matters.

// #define esp32autoreconnect    // implement esp32 autoreconnect event listener kludge, @DEPRECATED
// autoreconnect is WORKING https://github.com/espressif/arduino-esp32/issues/653#issuecomment-405604766

#define WM_WEBSERVERSHIM      // use webserver shim lib

#define WM_G(string_literal)  (String(FPSTR(string_literal)).c_str())

#ifdef ESP8266

    extern "C" {
      #include "user_interface.h"
    }
    #include <ESP8266WiFi.h>
    #include <ESP8266WebServer.h>

    #ifdef WM_MDNS
        #include <ESP8266mDNS.h>
    #endif

    #define WIFI_getChipId() ESP.getChipId() 
    #define WM_WIFIOPEN   ENC_TYPE_NONE

#elif defined(ESP32)

    #include <WiFi.h>
    #include <esp_wifi.h>  
    #include <Update.h>
    
    #define WIFI_getChipId() (uint32_t)ESP.getEfuseMac()
    #define WM_WIFIOPEN   WIFI_AUTH_OPEN

    #ifndef WEBSERVER_H
        #ifdef WM_WEBSERVERSHIM
            #include <WebServer.h>
        #else
            #include <ESP8266WebServer.h>
            // Forthcoming official ? probably never happening
            // https://github.com/esp8266/ESPWebServer
        #endif
    #endif

    #ifdef WM_ERASE_NVS
       #include <nvs.h>
       #include <nvs_flash.h>
    #endif

    #ifdef WM_MDNS
        #include <ESPmDNS.h>
    #endif

    #ifdef WM_RTC
        #ifdef ESP_IDF_VERSION_MAJOR // IDF 4+
        #if CONFIG_IDF_TARGET_ESP32 // ESP32/PICO-D4
        #include "esp32/rom/rtc.h"
        #elif CONFIG_IDF_TARGET_ESP32S2
        #include "esp32s2/rom/rtc.h"
        #elif CONFIG_IDF_TARGET_ESP32C3
        #include "esp32c3/rom/rtc.h"
        #elif CONFIG_IDF_TARGET_ESP32S3
        #include "esp32s3/rom/rtc.h"
        #else
        #error Target CONFIG_IDF_TARGET is not supported
        #endif
        #else // ESP32 Before IDF 4.0
        #include "rom/rtc.h"
        #endif
    #endif

#else
#endif

#include <DNSServer.h>
#include <memory>


// Include wm strings vars
// Pass in strings env override via LANG_XX
#if defined(LANG_DE)
  #include "wm_strings_de.h"
#elif defined(LANG_ES)
  #include "wm_strings_es.h"
#elif defined(LANG_EN)
  #include "wm_strings_en.h"
#elif defined(LANG_FR)
  #include "wm_strings_fr.h"
#elif defined(LANG_PT)
  #include "wm_strings_pt.h"
#elif defined(LANG_PT_BR)
  #include "wm_strings_pt_br.h"
#else
  #include "wm_strings_en.h"
#endif

// prep string concat vars
#define WM_STRING2(x) #x
#define WM_STRING(x) WM_STRING2(x)    

// #include <esp_idf_version.h>
#ifdef ESP_IDF_VERSION
    // #pragma message "ESP_IDF_VERSION_MAJOR = " WM_STRING(ESP_IDF_VERSION_MAJOR)
    // #pragma message "ESP_IDF_VERSION_MINOR = " WM_STRING(ESP_IDF_VERSION_MINOR)
    // #pragma message "ESP_IDF_VERSION_PATCH = " WM_STRING(ESP_IDF_VERSION_PATCH)
    #define VER_IDF_STR WM_STRING(ESP_IDF_VERSION_MAJOR)  "."  WM_STRING(ESP_IDF_VERSION_MINOR)  "."  WM_STRING(ESP_IDF_VERSION_PATCH)
#else 
    #define VER_IDF_STR "Unknown"
#endif

#ifdef Arduino_h
    #ifdef ESP32
    // #include "esp_arduino_version.h" // esp32 arduino > 2.x
    #endif
    // esp_get_idf_version
    #ifdef ESP_ARDUINO_VERSION
        // #pragma message "ESP_ARDUINO_VERSION_MAJOR = " WM_STRING(ESP_ARDUINO_VERSION_MAJOR)
        // #pragma message "ESP_ARDUINO_VERSION_MINOR = " WM_STRING(ESP_ARDUINO_VERSION_MINOR)
        // #pragma message "ESP_ARDUINO_VERSION_PATCH = " WM_STRING(ESP_ARDUINO_VERSION_PATCH)
        #ifdef ESP_ARDUINO_VERSION_MAJOR
        #define VER_ARDUINO_STR WM_STRING(ESP_ARDUINO_VERSION_MAJOR)  "."  WM_STRING(ESP_ARDUINO_VERSION_MINOR)  "."  WM_STRING(ESP_ARDUINO_VERSION_PATCH)
        #else
        #define VER_ARDUINO_STR "Unknown"
        #endif
    #else
        #include <core_version.h>
        // #pragma message "ESP_ARDUINO_VERSION_GIT  = " WM_STRING(ARDUINO_ESP32_GIT_VER)//  0x46d5afb1
        // #pragma message "ESP_ARDUINO_VERSION_DESC = " WM_STRING(ARDUINO_ESP32_GIT_DESC) //  1.0.6
        // #pragma message "ESP_ARDUINO_VERSION_REL  = " WM_STRING(ARDUINO_ESP32_RELEASE) //"1_0_6"
        #ifdef ESP_ARDUINO_VERSION_MAJOR
        #define VER_ARDUINO_STR WM_STRING(ESP_ARDUINO_VERSION_MAJOR)  "."  WM_STRING(ESP_ARDUINO_VERSION_MINOR)  "."  WM_STRING(ESP_ARDUINO_VERSION_PATCH)
        #else
        #define VER_ARDUINO_STR "Unknown"
        #endif
    #endif
#else 
#define VER_ARDUINO_STR "Unknown"
#endif

// #pragma message "VER_IDF_STR = " WM_STRING(VER_IDF_STR)
// #pragma message "VER_ARDUINO_STR = " WM_STRING(VER_ARDUINO_STR)

#ifndef WIFI_MANAGER_MAX_PARAMS
    #define WIFI_MANAGER_MAX_PARAMS 5 // params will autoincrement and realloc by this amount when max is reached
#endif

#define WFM_LABEL_BEFORE 1
#define WFM_LABEL_AFTER 2
#define WFM_NO_LABEL 0
#define WFM_LABEL_DEFAULT 1
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

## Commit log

2025-02-24 sharded for all version
    [esp32-clock.kicad_sch, supply.kicad_sch]
2026-07-16 Migrate build from PlatformIO/Arduino to native ESP-IDF (idf.py)
    Vendors arduino-esp32, TFT_eSPI and WiFiManager as ESP-IDF components under
    components/ (Arduino-as-component approach) so the existing main.cpp/
    WifiTimeLib.cpp application code needed no functional changes. src/ is
    renamed to main/ per ESP-IDF convention, and sdkconfig.defaults replaces
    platformio.ini's build_flags (TFT pinout/driver, partition table, flash
    size, selective Arduino library compilation to fit the app partition).
    [default_8MB_ffat.csv, gen4esp32_16MBapp.csv, gen4esp32_2MBapp_2MBota_12MBspiffs.csv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]
